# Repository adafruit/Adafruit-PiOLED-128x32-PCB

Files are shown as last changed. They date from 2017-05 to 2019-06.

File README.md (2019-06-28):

## Adafruit PiOLED 128x32 PCB

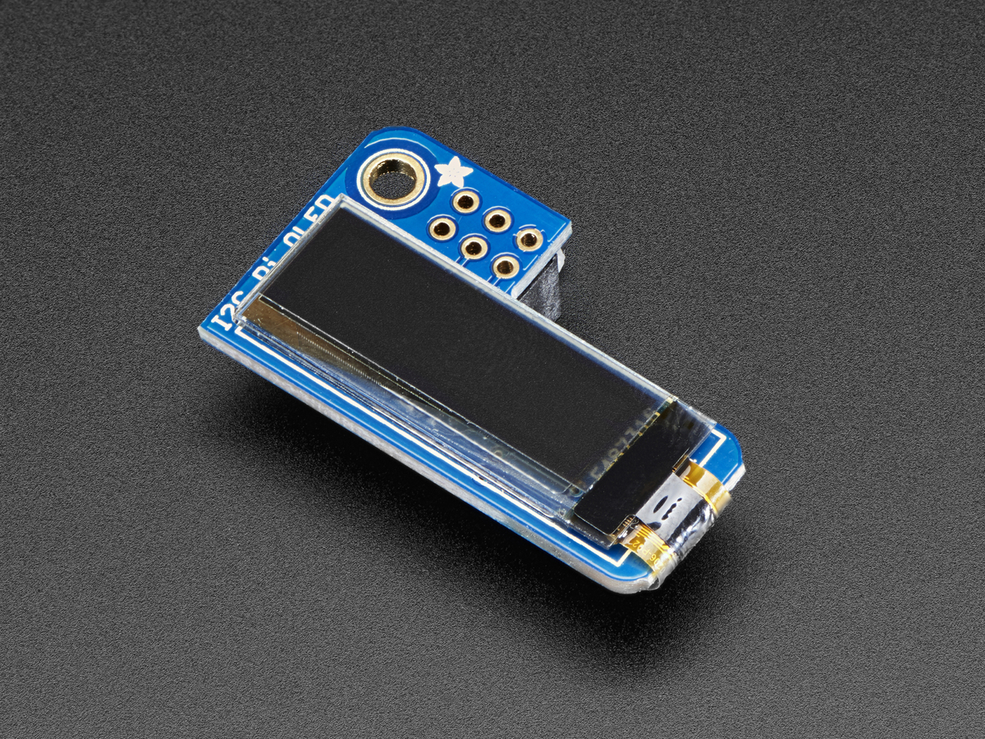
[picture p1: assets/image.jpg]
<a href="http://www.adafruit.com/products/3527"><br/>
Click here to purchase one from the Adafruit shop</a>

PCB files for the Adafruit PiOLED 128x32. Format is EagleCAD schematic and board layout
* http://www.adafruit.com/product/3527

### Description

If you're looking for the most compact li'l display for a Raspberry Pi (most likely a Pi Zero) project, this might be just the thing you need!

The Adafruit 128x32 PiOLED is your little OLED pal, ready to snap onto any and all Raspberry Pi computers, to give you a little display. The PiOLED comes with a monochrome 128x32 OLED, with sharp white pixels. The OLED uses only the I2C pins so you have plenty of GPIO connections available for buttons, LEDs, sensors, etc. It's also nice and compact so it will fit into any case.

These displays are small, only about 1" diagonal, but very readable due to the high contrast of an OLED display. This screen is made of 128x32 individual white OLED pixels and because the display makes its own light, no backlight is required. This reduces the power required to run the OLED and is why the display has such high contrast; we really like this miniature display for its crispness!

Using the display is very easy, we have a Python library for the SSD1306 chipset. Our example code allows you to draw images, text, whatever you like, using the Python imaging library. Our tests showed 30 FPS update rates so you can do animations or simple video.

Comes completely pre-assembled and tested so you don't need to do anything but plug it in and install our Python code! Works with any Raspberry Pi computer, including the original Pi 1, B+, Pi 2, Pi 3 and Pi Zero.

### License

Adafruit invests time and resources providing this open source design, please support Adafruit and open-source hardware by purchasing products from [Adafruit](https://www.adafruit.com)!

Designed by Limor Fried/Ladyada for Adafruit Industries.

Creative Commons Attribution/Share-Alike, all text above must be included in any redistribution. See license.txt for additional details.

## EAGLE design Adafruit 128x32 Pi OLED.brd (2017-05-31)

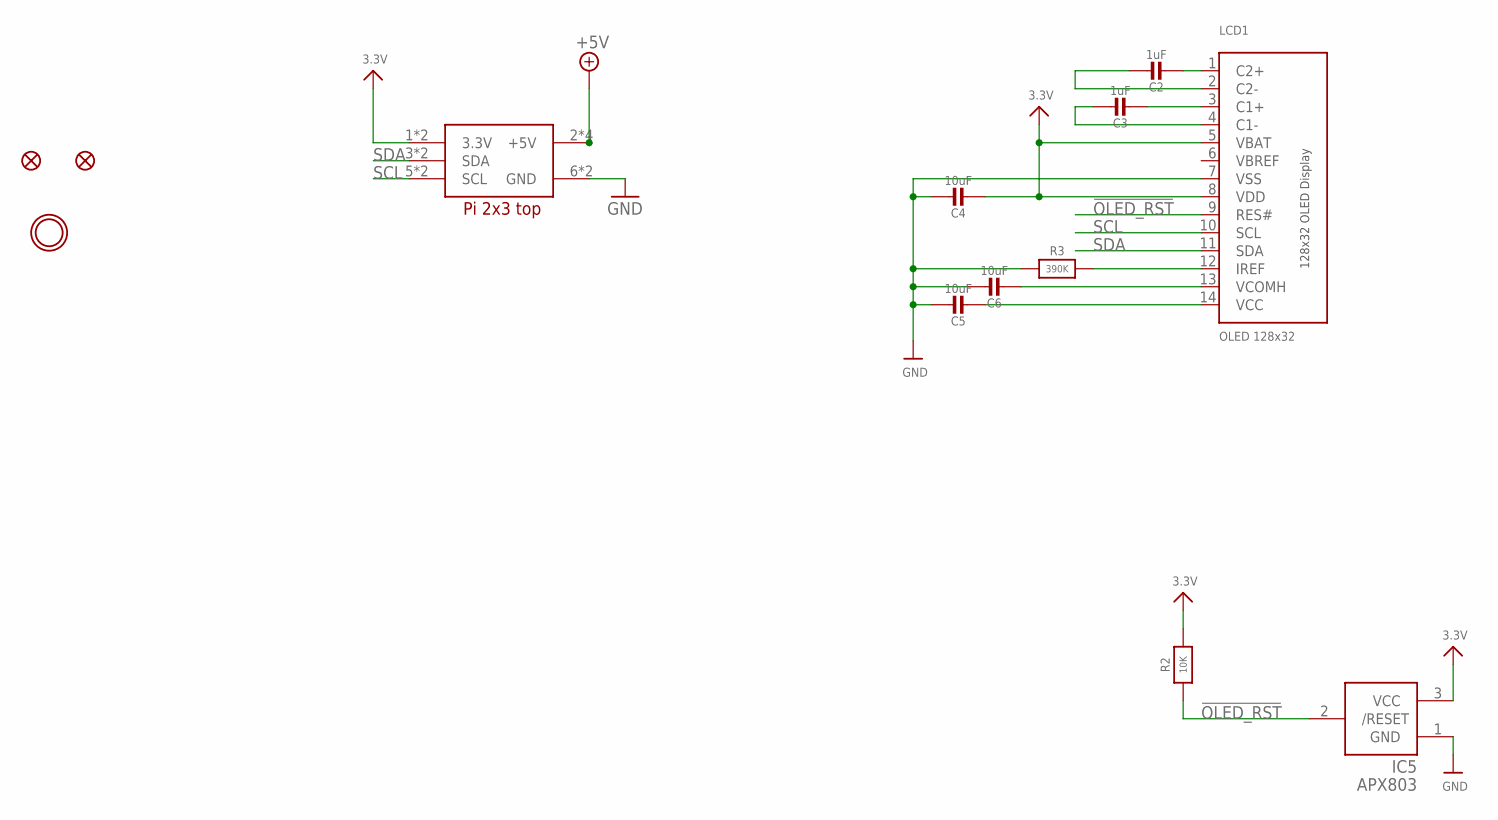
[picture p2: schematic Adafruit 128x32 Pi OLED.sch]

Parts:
C2, C3: 1uF; 0805-NO
C4, C5, C6: 10uF; 0805-NO
FID3, FID4: FIDUCIAL_1MM
IC5: APX803; SOT23
LCD1: OLED 128x32; UG-2832HSWEG02_WRAPUNDER
R2: 10K; 0805-NO
R3: 390K; 0805-NO
RPI1: RASPBERRYPI_2X3; RASPBERRYPI_2X3_THMSMT
U$4: MOUNTINGHOLE3.0THIN; MOUNTINGHOLE_3.0_PLATEDTHIN

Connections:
3.3V: C4.2, IC5.3 (VCC), LCD1.5 (VBAT), LCD1.8 (VDD), R2.2, RPI1.1 (3.3V), RPI1.1' (3.3V)
!OLED_RST: IC5.2 (/RESET), LCD1.9 (RES#), R2.1
+5V: RPI1.2 (+5V), RPI1.2' (+5V), RPI1.4 (+5V), RPI1.4' (+5V)
GND: C4.1, C5.1, C6.1, IC5.1 (GND), LCD1.7 (VSS), R3.1, RPI1.6 (GND), RPI1.6' (GND)
unnamed: C2.2, LCD1.1 (C2+)
unnamed: C2.1, LCD1.2 (C2-)
unnamed: C3.2, LCD1.3 (C1+)
unnamed: C3.1, LCD1.4 (C1-)
unnamed: C6.2, LCD1.13 (VCOMH)
unnamed: C5.2, LCD1.14 (VCC)
unnamed: LCD1.12 (IREF), R3.2
SCL: LCD1.10 (SCL), RPI1.5 (SCL), RPI1.5' (SCL)
SDA: LCD1.11 (SDA), RPI1.3 (SDA), RPI1.3' (SDA)
VBREF: LCD1.6 (VBREF)

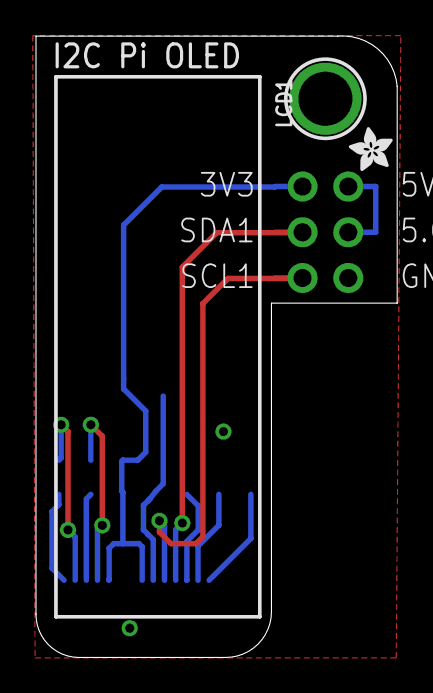
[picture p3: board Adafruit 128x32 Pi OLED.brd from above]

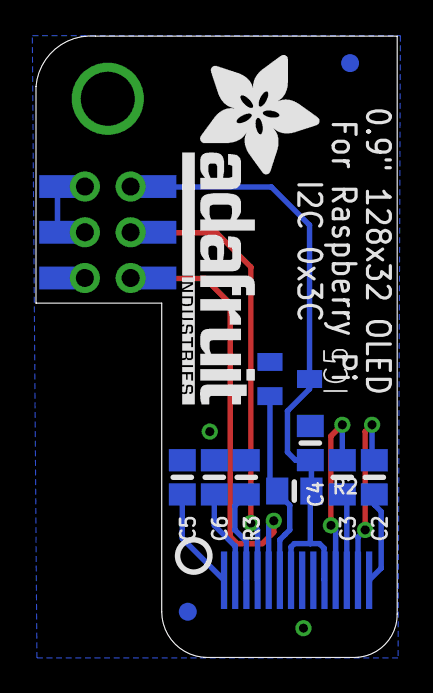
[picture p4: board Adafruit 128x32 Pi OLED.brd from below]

Board: 2 copper layers, 20.1 x 34.5 mm, 16 parts (12 on the bottom side), 13 nets.

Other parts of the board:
U$1: ADAFRUIT_2.5MM
U$3: PCBFEAT-REV-040
U$8: ADAFRUIT_TEXT_20MM

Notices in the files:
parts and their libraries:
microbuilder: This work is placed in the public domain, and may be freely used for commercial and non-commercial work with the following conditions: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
